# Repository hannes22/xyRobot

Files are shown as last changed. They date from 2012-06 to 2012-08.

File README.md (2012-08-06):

# xyRobot

xyRobot is the Framework for my Robot. [Visit my website for more informations](http://xythobuz.org/index.php?p=rob).

## Software used

 + [Peter Fleurys TWI Library](http://homepage.hispeed.ch/peterfleury/avr-software.html)
 + [Linux Version of Peter Danneggers 'fastboot' by H. C. Zimmerer](http://www.mikrocontroller.net/topic/146638)
 + [A Linux compatible Upload Software for fastboot](http://www.avrfreaks.net/index.php?module=Freaks%20Academy&func=viewItem&item_type=project&item_id=1927)

## xyRobotRemote

xyRobotRemote is a Java App which communicates with the Robot Firmware over a serial port. It allows you to shoot pictures with the Gameboy camera and remote-control the robot. It requires Java 6 and could possibly work with Java 7...

## Protocol

The protocol used by the xyRobot Firmware and xyRobotRemote to remote-control the robot is as follows.

<table>
<tr><th>Character Sequence</th><th>Action</th></tr>
<tr><td>ASCII '?'</td><td>Print Firmware Version String</td></tr>
<tr><td>0x80, x</td><td>Rotate the camera Up/Down to the position indicated by the next byte, x, (0 to 180)</td></tr>
<tr><td>0x81, x</td><td>Same as 0x80, but Left/Right</td></tr>
<tr><td>0x82, r1...r8</td><td>Send picture. Camera Register Settings set with the following 8 bytes.</td></tr>
<tr><td>0x83, d, s, dir</td><td>Drive dist cm with speed speed. Direction Forwards if dir = 1, Backwards if dir = 0</td></tr>
<tr><td>0x84, deg, dir</td><td>Rotate deg Degree. Direction Right if dir = 1, ;eft if dir = 0</td></tr>
<tr><td>0x85, r1...r8</td><td>Send picture with 4bit per Pixel.</td></tr>
<tr><td>0x86</td><td>Returns measured distance.</td></tr>
<tr><td>0x87, r1...r8</td><td>Send picture with 2bit per Pixel.</td></tr>
<tr><td>0x88, r1...r8</td><td>Send picture with 1bit per Pixel.</td></tr>
</table>

New major releases could change this protocol or make additions.

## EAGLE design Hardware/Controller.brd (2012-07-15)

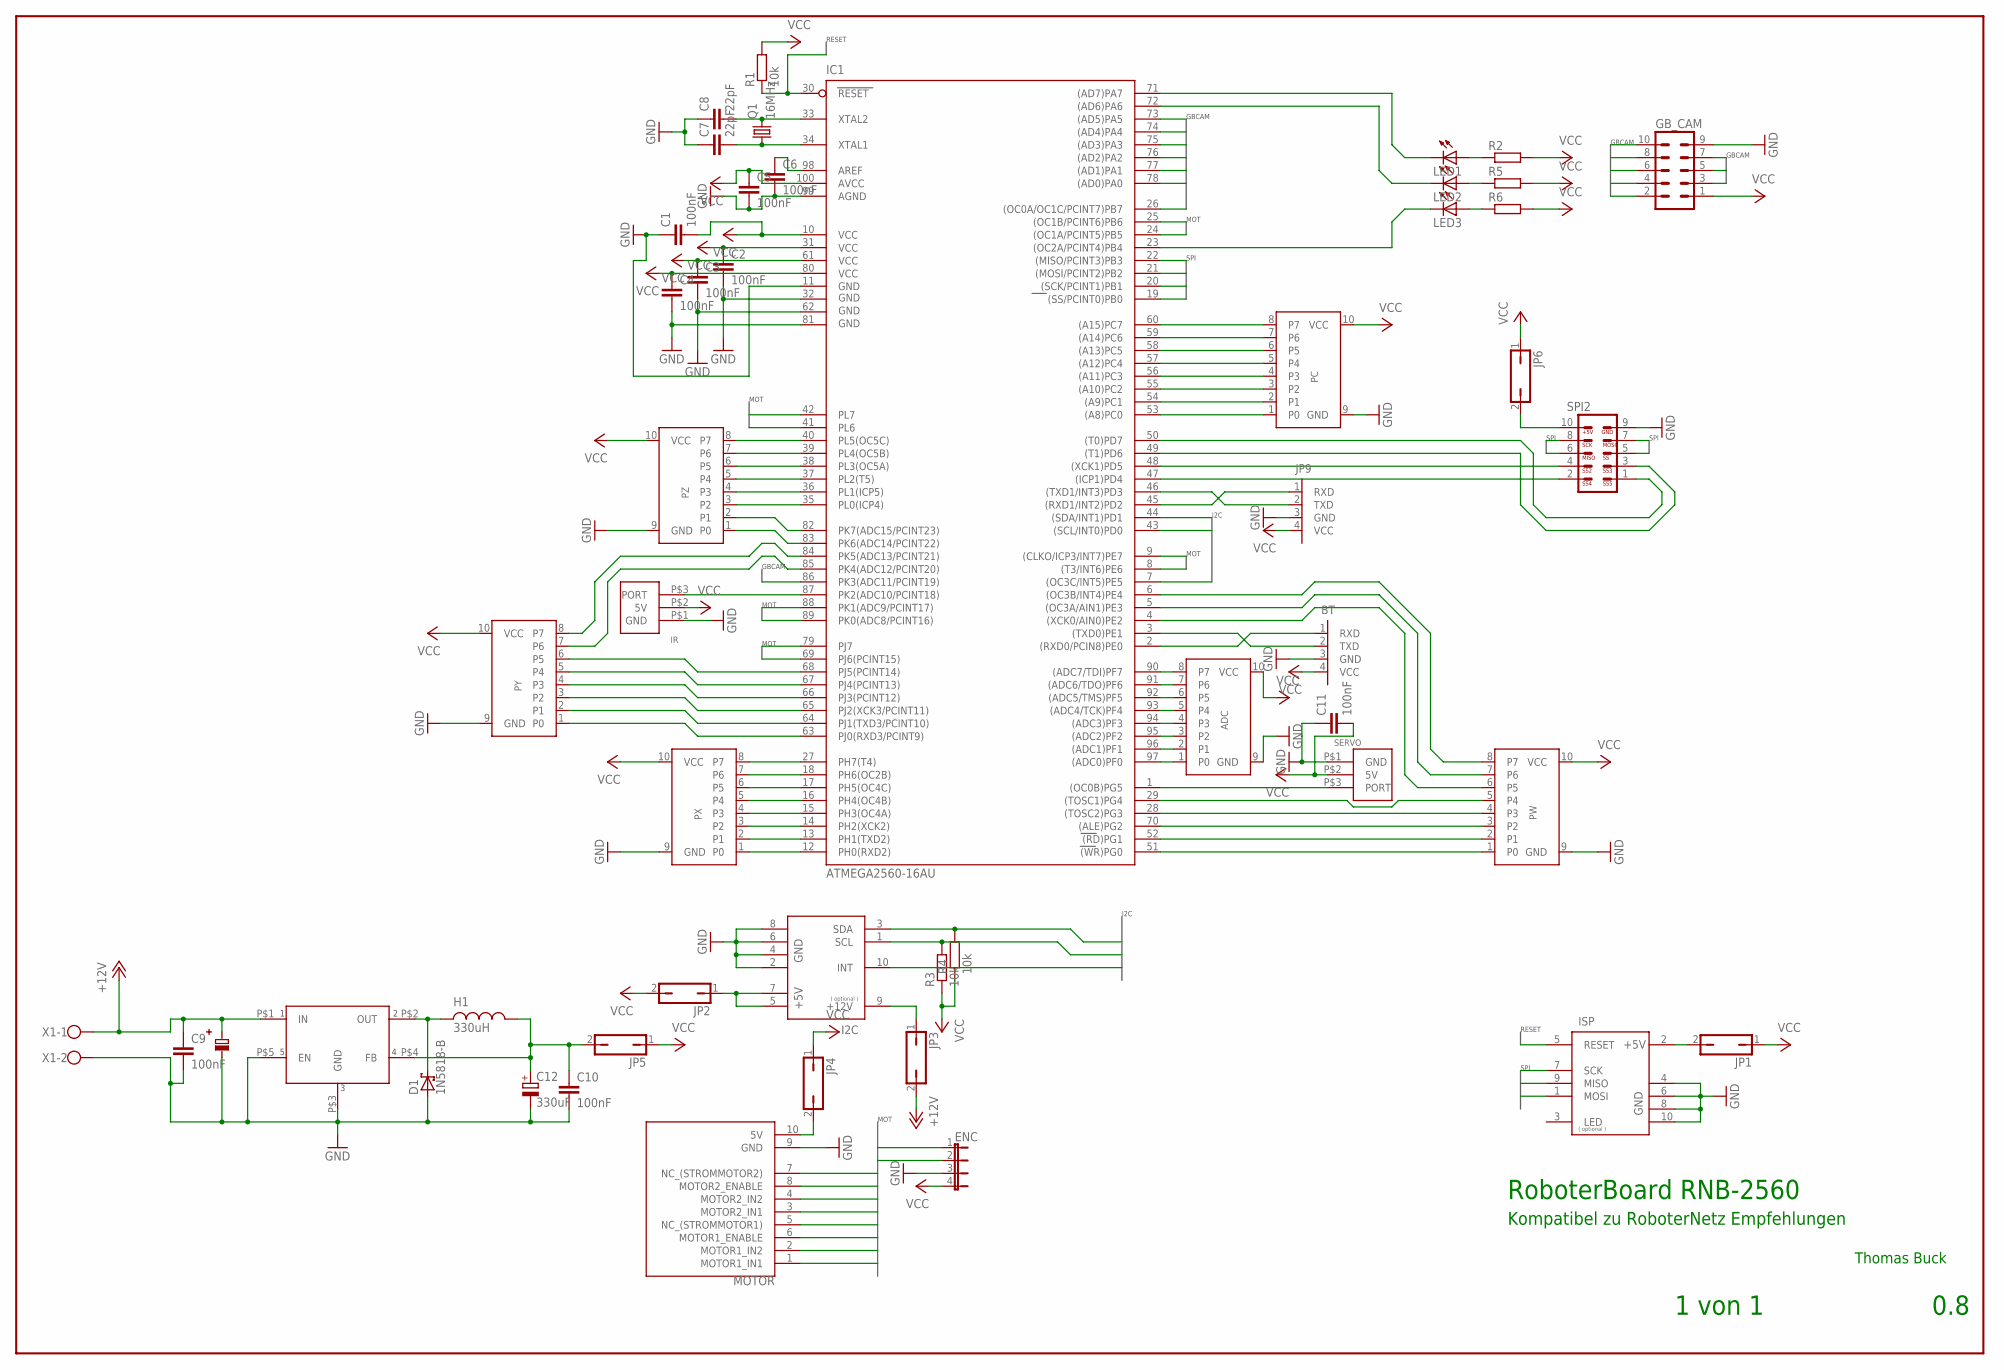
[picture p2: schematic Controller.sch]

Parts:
ADC: PORT; ML10
BT: RS232_TTL; 1X04
C1, C2, C3, C4, C5, C6, C9, C10, C11: 100nF; C0603
C7, C8: 22pF; C0603
C12: 330uF; PANASONIC_F
D1: 1N5818-B; DO41-7.6
ENC: JP4E; JP4
GB_CAM: ML10
H1: 330uH; PISR
I2C: I2C; ML10
IC1: ATMEGA2560-16AU; TQFP100
IR: UNIPORT3POL; 1X3SERVO
ISP: AVR-ISP; ML10
JP1, JP2, JP3, JP4, JP5, JP6: JP1Q; JP1
JP9: RS232_TTL; 1X04
LED1, LED2, LED3: LEDCHIP-LED0603; CHIP-LED0603
LM2576-5: LM2576; TO-220
MOTOR: MOTORSTTCKER10POLRNNORM; ML10
PC: PORT; ML10
PW: PORT; ML10
PX: PORT; ML10
PY: PORT; ML10
PZ: PORT; ML10
Q1: 16MHz; HC49/S
R1, R3, R4: 10k; R0603
R2, R5, R6: R-EU_R0603; R0603
SERVO: UNIPORT3POL; 1X3SERVO
SPI2: SPISTECKER; ML10
U$1: 100uF; ELKO_SMD_6.5
X1: W237-102

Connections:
+12V: C9.1, JP3.2, LM2576-5.P$1 (IN), U$1.P$2, X1.1
ANALOG: GB_CAM.8, IC1.86 (PK3(ADC11/PCINT19))
CLK: GB_CAM.6, IC1.77 ((AD1)PA1)
DATA: GB_CAM.3, IC1.74 ((AD4)PA4)
DATASET: GB_CAM.4, IC1.75 ((AD3)PA3)
DREHL: ENC.1, IC1.9 ((CLKO/ICP3/INT7)PE7)
DREHR: ENC.2, IC1.8 ((T3/INT6)PE6)
GND: ADC.9 (GND), BT.3 (GND), C1.1, C2.2, C3.2, C4.2, C5.2, C6.2, C7.1, C8.1, C9.2, C10.2, C11.1, C12.-, D1.A, ENC.3, GB_CAM.9, I2C.2 (GND), I2C.4 (GND), I2C.6 (GND), I2C.8 (GND), IC1.11 (GND), IC1.32 (GND1), IC1.62 (GND2), IC1.81 (GND3), IC1.99 (AGND), IR.P$1 (GND), ISP.4 (GND), ISP.6 (GND), ISP.8 (GND), ISP.10 (GND), JP9.3 (GND), LM2576-5.P$3 (GND), LM2576-5.P$5 (EN), MOTOR.9 (GND), PC.9 (GND), PW.9 (GND), PX.9 (GND), PY.9 (GND), PZ.9 (GND), SERVO.P$1 (GND), SPI2.9, U$1.P$1, X1.2
IN1L: IC1.42 (PL7), MOTOR.1 (MOTOR1_IN1)
IN1R: IC1.79 (PJ7), MOTOR.3 (MOTOR2_IN1)
IN2L: IC1.41 (PL6), MOTOR.2 (MOTOR1_IN2)
IN2R: IC1.69 (PJ6(PCINT15)), MOTOR.4 (MOTOR2_IN2)
INT: I2C.10 (INT), IC1.7 ((OC3C/INT5)PE5)
MISO: IC1.22 ((MISO/PCINT3)PB3), ISP.9 (MISO), SPI2.6
MOSI: IC1.21 ((MOSI/PCINT2)PB2), ISP.1 (MOSI), SPI2.7
unnamed: IC1.87 (PK2(ADC10/PCINT18)), IR.P$3 (PORT)
unnamed: C6.1, IC1.98 (AREF)
unnamed: C8.2, IC1.33 (XTAL2), Q1.2
unnamed: C7.2, IC1.34 (XTAL1), Q1.1
unnamed: IC1.1 ((OC0B)PG5), SERVO.P$3 (PORT)
unnamed: IC1.60 ((A15)PC7), PC.8 (P7)
unnamed: IC1.59 ((A14)PC6), PC.7 (P6)
unnamed: IC1.58 ((A13)PC5), PC.6 (P5)
unnamed: IC1.57 ((A12)PC4), PC.5 (P4)
unnamed: IC1.56 ((A11)PC3), PC.4 (P3)
unnamed: IC1.55 ((A10)PC2), PC.3 (P2)
unnamed: IC1.54 ((A9)PC1), PC.2 (P1)
unnamed: IC1.53 ((A8)PC0), PC.1 (P0)
unnamed: IC1.12 (PH0(RXD2)), PX.1 (P0)
unnamed: IC1.13 (PH1(TXD2)), PX.2 (P1)
unnamed: IC1.14 (PH2(XCK2)), PX.3 (P2)
unnamed: IC1.15 (PH3(OC4A)), PX.4 (P3)
unnamed: IC1.16 (PH4(OC4B)), PX.5 (P4)
unnamed: IC1.17 (PH5(OC4C)), PX.6 (P5)
unnamed: IC1.18 (PH6(OC2B)), PX.7 (P6)
unnamed: IC1.27 (PH7(T4)), PX.8 (P7)
unnamed: IC1.40 (PL5(OC5C)), PZ.8 (P7)
unnamed: IC1.39 (PL4(OC5B)), PZ.7 (P6)
unnamed: IC1.38 (PL3(OC5A)), PZ.6 (P5)
unnamed: IC1.37 (PL2(T5)), PZ.5 (P4)
unnamed: IC1.36 (PL1(ICP5)), PZ.4 (P3)
unnamed: IC1.35 (PL0(ICP4)), PZ.3 (P2)
unnamed: IC1.82 (PK7(ADC15/PCINT23)), PZ.2 (P1)
unnamed: IC1.83 (PK6(ADC14/PCINT22)), PZ.1 (P0)
unnamed: IC1.63 (PJ0(RXD3/PCINT9)), PY.1 (P0)
unnamed: IC1.64 (PJ1(TXD3/PCINT10)), PY.2 (P1)
unnamed: IC1.65 (PJ2(XCK3/PCINT11)), PY.3 (P2)
unnamed: IC1.66 (PJ3(PCINT12)), PY.4 (P3)
unnamed: IC1.67 (PJ4(PCINT13)), PY.5 (P4)
unnamed: IC1.68 (PJ5(PCINT14)), PY.6 (P5)
unnamed: IC1.85 (PK4(ADC12/PCINT20)), PY.7 (P6)
unnamed: IC1.84 (PK5(ADC13/PCINT21)), PY.8 (P7)
unnamed: IC1.51 ((WR)PG0), PW.1 (P0)
unnamed: IC1.52 ((RD)PG1), PW.2 (P1)
unnamed: IC1.70 ((ALE)PG2), PW.3 (P2)
unnamed: IC1.28 ((TOSC2)PG3), PW.4 (P3)
unnamed: IC1.29 ((TOSC1)PG4), PW.5 (P4)
unnamed: IC1.4 ((XCK0/AIN0)PE2), PW.6 (P5)
unnamed: IC1.5 ((OC3A/AIN1)PE3), PW.7 (P6)
unnamed: IC1.6 ((OC3B/INT4)PE4), PW.8 (P7)
unnamed: JP6.2, SPI2.10
unnamed: IC1.47 ((ICP1)PD4), SPI2.2
unnamed: IC1.48 ((XCK1)PD5), SPI2.4
unnamed: IC1.50 ((T0)PD7), SPI2.1
unnamed: IC1.23 ((OC2A/PCINT4)PB4), LED3.C
unnamed: IC1.72 ((AD6)PA6), LED2.C
unnamed: IC1.71 ((AD7)PA7), LED1.C
unnamed: IC1.49 ((T1)PD6), SPI2.3
unnamed: ISP.2 (+5V), JP1.2
unnamed: I2C.5 (+5V), I2C.7 (+5V), JP2.1
unnamed: I2C.9 (+12V), JP3.1
unnamed: JP4.2, MOTOR.10 (5V)
unnamed: ADC.8 (P7), IC1.90 ((ADC7/TDI)PF7)
unnamed: LED1.A, R2.1
unnamed: LED2.A, R5.1
unnamed: LED3.A, R6.1
unnamed: ADC.7 (P6), IC1.91 ((ADC6/TDO)PF6)
unnamed: ADC.6 (P5), IC1.92 ((ADC5/TMS)PF5)
unnamed: D1.C, H1.P$1, LM2576-5.P$2 (OUT)
unnamed: ADC.5 (P4), IC1.93 ((ADC4/TCK)PF4)
unnamed: ADC.4 (P3), IC1.94 ((ADC3)PF3)
unnamed: ADC.3 (P2), IC1.95 ((ADC2)PF2)
unnamed: ADC.2 (P1), IC1.96 ((ADC1)PF1)
unnamed: ADC.1 (P0), IC1.97 ((ADC0)PF0)
unnamed: IC1.46 ((TXD1/INT3)PD3), JP9.2 (TXD)
unnamed: IC1.45 ((RXD1/INT2)PD2), JP9.1 (RXD)
unnamed: C10.1, C12.+, H1.P$2, JP5.2, LM2576-5.P$4 (FB)
PWML: IC1.25 ((OC1B/PCINT6)PB6), MOTOR.6 (MOTOR1_ENABLE)
PWMR: IC1.24 ((OC1A/PCINT5)PB5), MOTOR.8 (MOTOR2_ENABLE)
READIMG: GB_CAM.7, IC1.78 ((AD0)PA0)
RESET: IC1.30 (RESET), ISP.5 (RESET), R1.1
RX: BT.1 (RXD), IC1.2 ((RXD0/PCIN8)PE0)
SCK: IC1.20 ((SCK/PCINT1)PB1), ISP.7 (SCK), SPI2.8
SCL: I2C.1 (SCL), IC1.43 ((SCL/INT0)PD0), R3.2
SDA: I2C.3 (SDA), IC1.44 ((SDA/INT1)PD1), R4.2
SENSL: IC1.88 (PK1(ADC9/PCINT17)), MOTOR.5 (NC_(STROMMOTOR1))
SENSR: IC1.89 (PK0(ADC8/PCINT16)), MOTOR.7 (NC_(STROMMOTOR2))
SERVO: GB_CAM.10, IC1.26 ((OC0A/OC1C/PCINT7)PB7)
SS: IC1.19 ((SS/PCINT0)PB0), SPI2.5
START: GB_CAM.2, IC1.73 ((AD5)PA5)
SYSRES: GB_CAM.5, IC1.76 ((AD2)PA2)
TX: BT.2 (TXD), IC1.3 ((TXD0)PE1)
VCC: ADC.10 (VCC), BT.4 (VCC), C1.2, C2.1, C3.1, C4.1, C5.1, C11.2, ENC.4, GB_CAM.1, IC1.10 (VCC), IC1.31 (VCC1), IC1.61 (VCC2), IC1.80 (VCC3), IC1.100 (AVCC), IR.P$2 (5V), JP1.1, JP2.2, JP4.1, JP5.1, JP6.1, JP9.4 (VCC), PC.10 (VCC), PW.10 (VCC), PX.10 (VCC), PY.10 (VCC), PZ.10 (VCC), R1.2, R2.2, R3.1, R4.1, R5.2, R6.2, SERVO.P$2 (5V)

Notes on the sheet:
RoboterBoard RNB-2560
Thomas Buck
Kompatibel zu RoboterNetz Empfehlungen
0.8
MOT
I2C
SPI
RESET
GBCAM
1 von 1

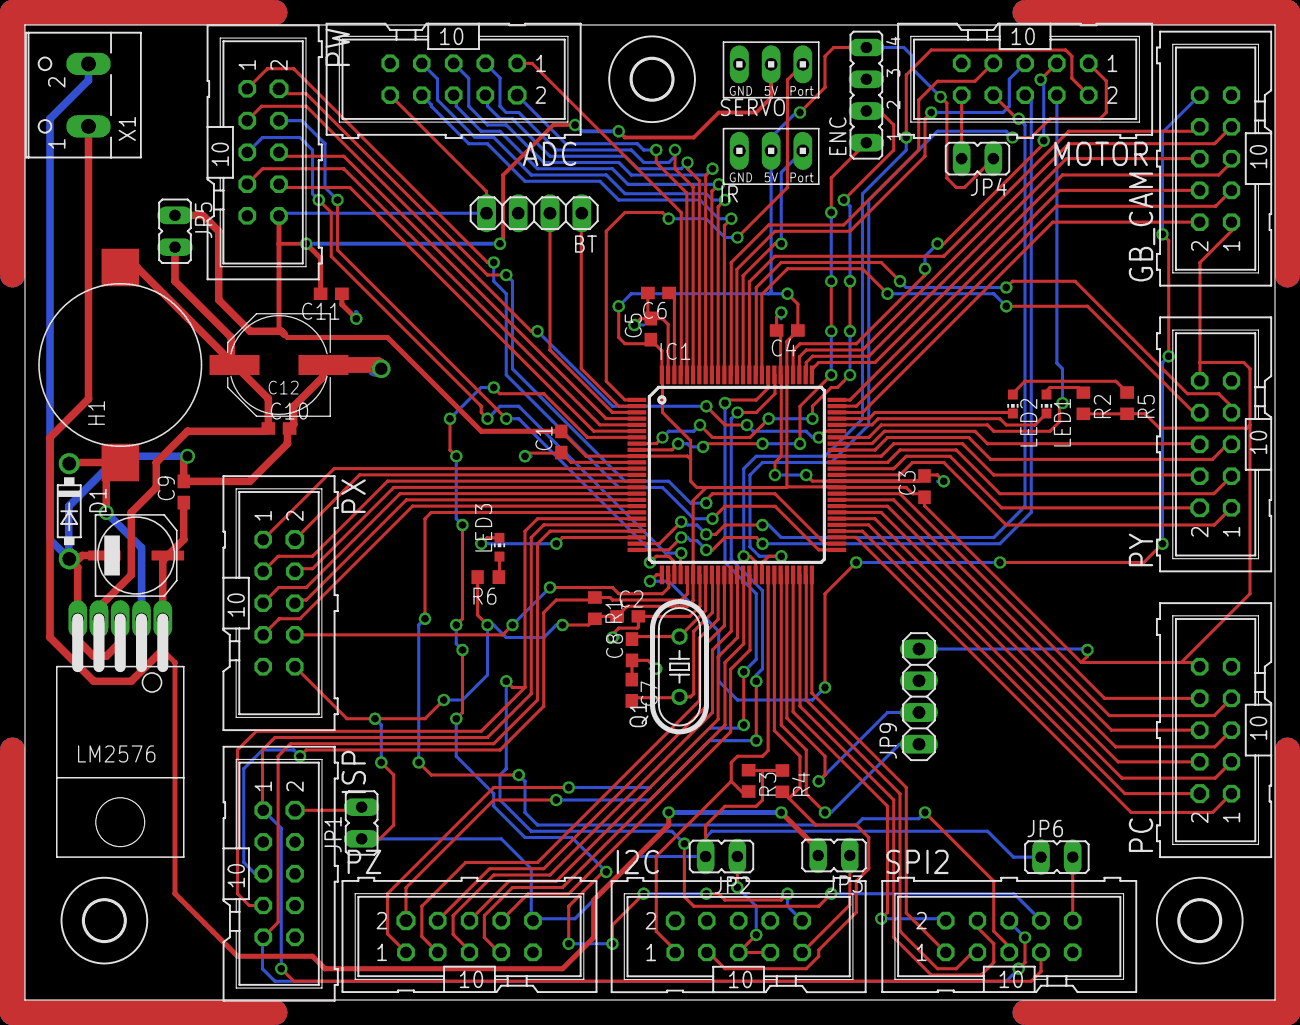
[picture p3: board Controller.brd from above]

Board: 2 copper layers, 100.0 x 78.0 mm, 53 parts (0 on the bottom side), 103 nets.

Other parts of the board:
U$2, U$3, U$4: 3,2

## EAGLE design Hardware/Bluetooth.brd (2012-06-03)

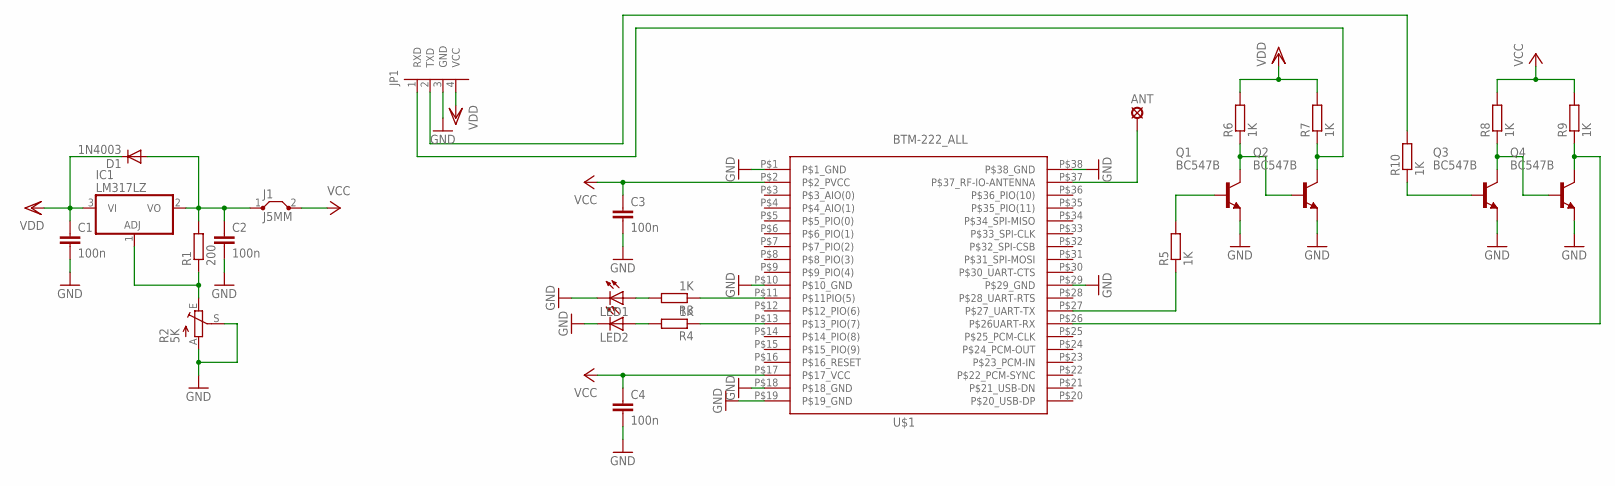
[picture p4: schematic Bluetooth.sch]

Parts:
ANT: SE14
C1, C2, C3, C4: 100n; C050-030X075
D1: 1N4003; DO41-10
IC1: LM317LZ; TO92
J1: J5MM; 05
JP1: RS232_TTL; 1X04
LED1, LED2: LED3MM
Q1, Q2, Q3, Q4: BC547B; TO92
R1: 200; 0207/10
R2: 5K; PT-10S
R3, R4, R5, R6, R7, R8, R9, R10: 1K; 0207/10
U$1: BTM-222_ALL; BTM-222

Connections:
GND: C1.2, C2.2, C3.2, C4.2, JP1.3 (GND), LED1.K (C), LED2.K (C), Q1.1 (E), Q2.1 (E), Q3.1 (E), Q4.1 (E), R2.A, R2.S, U$1.P$1 (P$1_GND), U$1.P$10 (P$10_GND), U$1.P$18 (P$18_GND), U$1.P$19 (P$19_GND), U$1.P$29 (P$29_GND), U$1.P$38 (P$38_GND)
unnamed: R3.1, U$1.P$11 (P$11PIO(5))
unnamed: LED1.A, R3.2
unnamed: IC1.1 (ADJ), R1.1, R2.E
unnamed: R4.1, U$1.P$13 (P$13_PIO(7))
unnamed: LED2.A, R4.2
unnamed: Q1.2 (B), R5.2
unnamed: JP1.1 (RXD), Q2.3 (C), R7.1
unnamed: Q1.3 (C), Q2.2 (B), R6.1
unnamed: JP1.2 (TXD), R10.2
unnamed: Q3.2 (B), R10.1
unnamed: R5.1, U$1.P$27 (P$27_UART-TX)
unnamed: Q3.3 (C), Q4.2 (B), R8.1
unnamed: Q4.3 (C), R9.1, U$1.P$26 (P$26UART-RX)
unnamed: ANT.MP, U$1.P$37 (P$37_RF-IO-ANTENNA)
unnamed: C2.1, D1.A, IC1.2 (VO), J1.1, R1.2
VCC: C3.1, C4.1, J1.2, R8.2, R9.2, U$1.P$2 (P$2_PVCC), U$1.P$17 (P$17_VCC)
VDD: C1.1, D1.C, IC1.3 (VI), JP1.4 (VCC), R6.2, R7.2

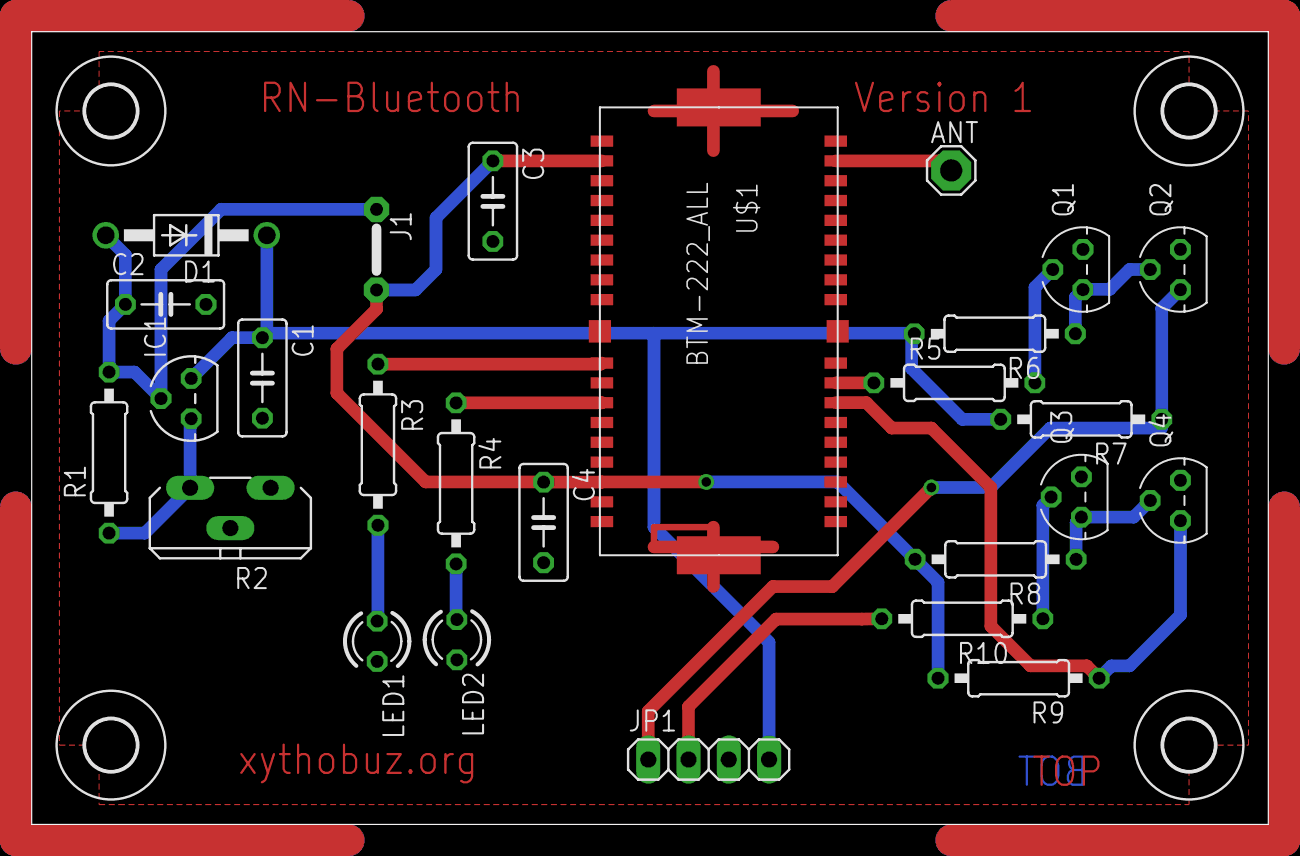
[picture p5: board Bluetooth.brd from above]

Board: 2 copper layers, 78.0 x 50.0 mm, 30 parts (0 on the bottom side), 18 nets.

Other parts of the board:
U$2, U$3, U$4, U$5: 3,2

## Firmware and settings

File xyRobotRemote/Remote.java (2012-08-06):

/*
 * Remote.java
 *
 * Copyright 2012 Thomas Buck <xythobuz@me.com>
 *
 * This file is part of xyRobot.
 *
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
 * You should have received a copy of the GNU General Public License
 * along with xyRobot.  If not, see <http://www.gnu.org/licenses/>.
 */

import javax.swing.*;
import javax.swing.event.*;
import java.awt.*;
import java.awt.event.*;
import javax.imageio.*;
import java.io.*;

public class Remote extends JFrame implements ActionListener, ChangeListener,
												MouseListener, KeyListener,
												ComponentListener {

	private final String version = "1.0";
	public int width = 485 + DistanceWindow.width;
	public int height = 420;
	public final int xOff = 0;
	public final int yOff = 0;

	private PaintCanvas canvas = null;

	private JPanel bigPanel = null;

	private JPanel serialStuff = null;
	private JComboBox portSelector = null;
	private JButton openPort = null;
	private JButton closePort = null;

	private JLabel status = null;

	private JPanel cameraStuff = null;
	private JButton trigger = null;
	private JSlider depth = null;
	private JButton save = null;
	private JSlider camMoveX = null;
	private JSlider camMoveY = null;
	private JButton camSettings = null;

	private JPanel driveStuff = null;
	private JTextField dist = null;
	private JLabel distCM = null;
	private JTextField speed = null;
	private JCheckBox reverse = null;
	private JButton drive = null;
	private JTextField degree = null;
	private JLabel degreeDeg = null;
	private JButton turnRight = null;
	private JButton turnLeft = null;

	public CanvasWindow canvasWin = null;
	public DistanceWindow distanceWin = null;

	public SerialCommunicator serial = null;

	private final int UP    = 0;
	private final int DOWN  = 1;
	private final int LEFT  = 2;
	private final int RIGHT = 3;

	private int registers[] = {
		0x00, // Z & Offset
		0x03, // N & VH & Gain
		0x00, // C1
		0x01, // C0
		0x01, // P
		0x00, // M
		0x01, // X
		0x04  // E & I & V
	};

	public Remote() {
		super("xyRobotRemote");

		serial = new SerialCommunicator(this);

		setBounds(xOff, yOff, width, height);
		setDefaultCloseOperation(JFrame.EXIT_ON_CLOSE);
		setLayout(null);
		addComponentListener(this);
		Container c = getContentPane();

		distanceWin = new DistanceWindow(this, 80);
		distanceWin.setBounds(0, 0, distanceWin.width, height);
		distanceWin.setVal(80);
		c.add(distanceWin);

		bigPanel = new JPanel();
		bigPanel.setBounds(distanceWin.width, 0, width - distanceWin.width, height);
		bigPanel.addKeyListener(this);
		bigPanel.setLayout(new FlowLayout());
		c.add(bigPanel);

		canvas = new PaintCanvas(128, 128, 2);
		// canvas.setBounds(10, 10, 256, 256);
		canvas.setPreferredSize(new Dimension(256, 256));
		canvas.setBorder(BorderFactory.createLoweredBevelBorder());
		canvas.addMouseListener(this);
		canvas.addKeyListener(this);
		bigPanel.add(canvas);

		cameraStuff = new JPanel();
		cameraStuff.setBorder(BorderFactory.createTitledBorder("Camera"));
		// cameraStuff.setBounds(275, 105, 215, 225);
		cameraStuff.setPreferredSize(new Dimension(215, 225));
		cameraStuff.setLayout(null);
		cameraStuff.addKeyListener(this);
		bigPanel.add(cameraStuff);

		serialStuff = new JPanel();
		serialStuff.setBorder(BorderFactory.createTitledBorder("Serial"));
		// serialStuff.setBounds(275, 5, 215, 95);
		serialStuff.setPreferredSize(new Dimension(215, 95));
		serialStuff.setLayout(null);
		serialStuff.addKeyListener(this);
		bigPanel.add(serialStuff);

		driveStuff = new JPanel();
		driveStuff.setBorder(BorderFactory.createTitledBorder("Drive"));
		// driveStuff.setBounds(275, 330, 215, 100);
		driveStuff.setPreferredSize(new Dimension(215, 100));
		driveStuff.setLayout(null);
		driveStuff.addKeyListener(this);
		bigPanel.add(driveStuff);

		status = new JLabel("<html>Initializing xyRobotRemote " + version);
		// status.setBounds(10, 275, 256, 50);
		// status.setSize(new Dimension(256, 50));
		status.addKeyListener(this);
		status.setBorder(BorderFactory.createLoweredBevelBorder());
		bigPanel.add(status);

		// --------------------------------

		String[] ports = HelperUtility.getPorts();
		if ((ports == null) || (ports.length == 0)) {
			showError("No serial ports found!");
			System.exit(1);
		}
		java.util.List<String> list = java.util.Arrays.asList(ports);
		java.util.Collections.reverse(list);
		ports = (String[])list.toArray();
		for (int i = 0; i < ports.length; i++) {
			if (ports[i].equals("/dev/tty.xyRobot-DevB") && (i != 0)) {
				String tmp = ports[0];
				ports[0] = ports[i];
				ports[i] = tmp;
			}
		}
		portSelector = new JComboBox(ports);
		portSelector.setBounds(5, 20, 205, 30);
		portSelector.addKeyListener(this);
		serialStuff.add(portSelector);

		openPort = new JButton();
		openPort.setText("Open");
		openPort.setBounds(5, 55, 100, 30);
		openPort.addActionListener(this);
		openPort.addKeyListener(this);
		serialStuff.add(openPort);

		closePort = new JButton();
		closePort.setText("Close");
		closePort.setBounds(105, 55, 100, 30);
		closePort.addActionListener(this);
		closePort.addKeyListener(this);
		serialStuff.add(closePort);

		trigger = new JButton();
		trigger.setText("Shoot Pic");
		trigger.setBounds(60, 15, 140, 30);
		trigger.addActionListener(this);
		trigger.addKeyListener(this);
		cameraStuff.add(trigger);

		camSettings = new JButton();
		camSettings.setText("Cam Registers");
		camSettings.setBounds(60, 95, 140, 30);
		camSettings.addActionListener(this);
		camSettings.addKeyListener(this);
		cameraStuff.add(camSettings);

		save = new JButton();
		save.setText("Save image");
		save.setBounds(60, 130, 140, 30);
		save.addActionListener(this);
		save.addKeyListener(this);
		cameraStuff.add(save);

		depth = new JSlider(0, 3);
		depth.setValue(3);
		depth.addChangeListener(this);
		depth.setBounds(60, 50, 140, 40);
		depth.setMajorTickSpacing(1);
		depth.setMajorTickSpacing(1);
		depth.setPaintTicks(true);
		java.util.Hashtable<Integer, JLabel> table = new java.util.Hashtable<Integer, JLabel>();
		table.put(0, new JLabel("1"));
		table.put(1, new JLabel("2"));
		table.put(2, new JLabel("4"));
		table.put(3, new JLabel("8"));
		depth.setLabelTable(table);
		depth.setPaintLabels(true);
		depth.addKeyListener(this);
		cameraStuff.add(depth);

		camMoveY = new JSlider(JSlider.VERTICAL, 0, 180, 40); // vertical cam movement slider
		camMoveY.setBounds(5, 15, 60, 205);
		camMoveY.addChangeListener(this);
		camMoveY.setMajorTickSpacing(45);
		camMoveY.setMinorTickSpacing(45);
		camMoveY.setPaintTicks(true);
		camMoveY.addKeyListener(this);
		cameraStuff.add(camMoveY);

		camMoveX = new JSlider(0, 180);
		camMoveX.setValue(95);
		camMoveX.setBounds(60, 165, 150, 60);
		camMoveX.addChangeListener(this);
		camMoveX.setMajorTickSpacing(45);
		camMoveX.setMinorTickSpacing(45);
		camMoveX.setPaintTicks(true);
		camMoveX.addKeyListener(this);
		cameraStuff.add(camMoveX);

		dist = new JTextField();
		dist.setText("100");
		dist.setBounds(5, 20, 40, 30);
		dist.addKeyListener(this);
		driveStuff.add(dist);

		distCM = new JLabel();
		distCM.setText("cm");
		distCM.setBounds(45, 20, 20, 30);
		distCM.addKeyListener(this);
		driveStuff.add(distCM);

		speed = new JTextField();
		speed.setText("200");
		speed.setBounds(70, 20, 40, 30);
		speed.addKeyListener(this);
		driveStuff.add(speed);

		reverse = new JCheckBox();
		reverse.setBounds(115, 20, 30, 30);
		reverse.addKeyListener(this);
		driveStuff.add(reverse);

		drive = new JButton();
		drive.setText("Drive");
		drive.setBounds(150, 20, 60, 30);
		drive.addActionListener(this);
		drive.addKeyListener(this);
		driveStuff.add(drive);

		degree = new JTextField();
		degree.setText("180");
		degree.setBounds(15, 55, 40, 30);
		degree.addKeyListener(this);
		driveStuff.add(degree);

		degreeDeg = new JLabel();
		degreeDeg.setText("\u00b0");
		degreeDeg.setBounds(55, 55, 30, 30);
		degreeDeg.addKeyListener(this);
		driveStuff.add(degreeDeg);

		turnLeft = new JButton();
		turnLeft.setText("L");
		turnLeft.setBounds(80, 55, 50, 30);
		turnLeft.addActionListener(this);
		turnLeft.addKeyListener(this);
		driveStuff.add(turnLeft);

		turnRight = new JButton();
		turnRight.setText("R");
		turnRight.setBounds(135, 55, 50, 30);
		turnRight.addActionListener(this);
		turnRight.addKeyListener(this);
		driveStuff.add(turnRight);

		setControls(false); // Turn everything off
		setVisible(true);

		// Shutdown Hook to close an opened serial port
		Runtime.getRuntime().addShutdownHook(new Thread(new ShutdownThread(this), "Serial Closer"));

		log("Rendering Image");
		ImageTest t = new ImageTest("splash.png");
		canvas.setData(t.getData());
		fixImageColor(false); // Converting color-pics leads to dark images...
	}

	// ------------------------------
	// |            Misc            |
	// ------------------------------

	public void setControls(boolean open) {
		closePort.setEnabled(open);
		openPort.setEnabled(!open);
		trigger.setEnabled(open);
		// save.setEnabled(open);
		camMoveX.setEnabled(open);
		camMoveY.setEnabled(open);
		// camSettings.setEnabled(open);
		drive.setEnabled(open);
		reverse.setEnabled(open);
		speed.setEnabled(open);
		dist.setEnabled(open);
		degree.setEnabled(open);
		turnRight.setEnabled(open);
		turnLeft.setEnabled(open);
		depth.setEnabled(open);
	}

	private void setDistanceView() {
		serial.writeChar(0x86);
		short[] dist = serial.readData(1);
		distanceWin.setVal(dist[0]);
	}

	public void showError(String error) {
		JOptionPane.showMessageDialog(this, error, "Error", JOptionPane.ERROR_MESSAGE);
		log("ERROR: " + error);
	}

	public void showInfo(String info) {
		JOptionPane.showMessageDialog(this, info, "Info", JOptionPane.INFORMATION_MESSAGE);
		log(info);
	}

	public void log(String log) {
		String s = status.getText();
		if (s.length() > 50) {
			status.setText("<html>" + log);
		} else {
			status.setText(s + " -- " + log);
		}
	}

	private void readFile(String f) {
		try {
			FileReader fr = new FileReader(f);
			readFile(fr);
		} catch (Exception e) {
			System.out.println("Error: " + e.getMessage());
		}
	}

	private void readFile(InputStream is) {
		InputStreamReader isr = new InputStreamReader(is);
		readFile(isr);
	}

	private void readFile(Reader r) {
		try {
			BufferedReader br = new BufferedReader(r);
			java.util.ArrayList<String> l = new java.util.ArrayList<String>();
			String str, delimiter = ",\n";
			while ((str = br.readLine()) != null) {
				java.util.StringTokenizer t = new java.util.StringTokenizer(str, delimiter);
				while (t.hasMoreTokens()) {
					String element = t.nextToken();
					l.add(element);
				}
			}
			canvas.setData(l.toArray());
		} catch (Exception e) {
			System.out.println("Error: " + e.getMessage());
		}
	}

	private	void printImageStats() {
		int average = 0, max = 0, min = 256;
		for (int i = 0; i < 128; i++) {
			for (int j = 0; j < 128; j++) {
				if (canvas.data[i][j] > max) {
					max = canvas.data[i][j];
				}
				if (canvas.data[i][j] < min) {
					min = canvas.data[i][j];
				}

				average += canvas.data[i][j];
			}
		}
		average /= (128 * 128);

		System.out.println("Current Image Statistics:");
		System.out.println("Average: " + average);
		System.out.println("Maximum: " + max);
		System.out.println("Minimum: " + min);
	}

	private void fixImageColor(boolean print) {
		int max = 0;
		for (int i = 0; i < 128; i++) {
			for (int j = 0; j < 128; j++) {
				if (canvas.data[i][j] > max) {
					max = canvas.data[i][j];
				}
			}
		}
		if (max < 255) {
			double f = (double)255 / (double)max;
			for (int i = 0; i < 128; i++) {
				for (int j = 0; j < 128; j++) {
					canvas.data[i][j] *= f;
					if (canvas.data[i][j] > 255) {
						canvas.data[i][j] = 255;
					}
				}
			}
			canvas.repaint();
			if (print) System.out.printf("Image fixed. Factor: %.2f\n", f);
		}
	}

	// ------------------------------
	// | Calls for external windows |
	// ------------------------------

	public void distanceWindowKilled() {
		distanceWin = new DistanceWindow(this);
		if (serial.isOpen()) {
			setDistanceView();
		}
	}

	public void cameraWindowKilled() {
		canvasWin = null;
		canvas.setToRefresh(null);
	}

	public void registersUpdated(int[] regs) {
		registers = regs;
	}

	// ------------------------------
	// |         Listeners          |
	// ------------------------------

	public void actionPerformed(ActionEvent e) {
		if (e.getSource().equals(turnRight)) {
			turnButton(true);
		} else if (e.getSource().equals(turnLeft)) {
			turnButton(false);
		} else if (e.getSource().equals(drive)) {
			driveButton();
		} else if (e.getSource().equals(camSettings)) {
			camSettingsButton();
		} else if (e.getSource().equals(trigger)) {
			triggerButton();
		} else if (e.getSource().equals(openPort)) {
			openButton();
		} else if (e.getSource().equals(closePort)) {
			closeButton();
		} else if (e.getSource().equals(save)) {
			saveButton();
		}
	}

	public void keyTyped(KeyEvent e) {
		switch (e.getKeyChar()) {
			case 'r':
				canvas.randomize();
				break;

			case 's':
				printImageStats();
				break;

			case 'd':
				fixImageColor(true);
				break;

			case 'w':
				System.out.println(getWidth() + "x" + getHeight());
				break;
		}
	}
	public void keyPressed(KeyEvent e) {}
	public void keyReleased(KeyEvent e) {}

	public void mouseClicked(MouseEvent e) {
		if (e.getSource().equals(canvas)) {
			if (e.getClickCount() == 2) {
				if (canvasWin == null) {
					canvasWin = new CanvasWindow(this);
					canvas.setToRefresh(canvasWin.getCanvas());
					canvasWin.getCanvas().setData(canvas.data);
				}
			}
		}
	}
	public void mousePressed(MouseEvent e) {}
	public void mouseReleased(MouseEvent e) {}
	public void mouseEntered(MouseEvent e) {}
	public void mouseExited(MouseEvent e) {}

	public void componentResized(ComponentEvent e) {
		width = getWidth();
		height = getHeight();

		DistanceWindow dW = new DistanceWindow(this, 80);
		dW.setVal(distanceWin.value);
		getContentPane().remove(distanceWin);
		distanceWin = dW;
		distanceWin.setBounds(0, 0, distanceWin.width, height);
		getContentPane().add(distanceWin);

		bigPanel.setBounds(distanceWin.width, 0, width - distanceWin.width, height);

		repaint();
	}
	public void componentHidden(ComponentEvent e) {}
	public void componentMoved(ComponentEvent e) {}
	public void componentShown(ComponentEvent e) {}

	public void stateChanged(ChangeEvent e) {
		// For the sliders
		if (e.getSource().equals(camMoveY)) {
			if (!((JSlider)e.getSource()).getValueIsAdjusting()) {
				// New Y-Axis position
				serial.writeChar(0x80);
				serial.writeChar(camMoveY.getValue());
			}
		} else if (e.getSource().equals(camMoveX)) {
			if (!((JSlider)e.getSource()).getValueIsAdjusting()) {
				// New X-Axis position
				serial.writeChar(0x81);
				serial.writeChar(camMoveX.getValue());
			}
		}
	}

	// ------------------------------
	// |      Button Handler        |
	// ------------------------------

	private void triggerButton() {
		int length = 0;
		switch(depth.getValue()) {
			case 0:
				serial.writeChar(0x88);
				length = 64 * 32;
				break;
			case 1:
				serial.writeChar(0x87);
				length = 64 * 64;
				break;
			case 2:
				serial.writeChar(0x85);
				length = 128 * 64;
				break;
			case 3:
				serial.writeChar(0x82);
				length = 128 * 128;
				break;
		}
		log("Writing registers.");
		for (int i = 0; i < 8; i++) {
			serial.writeChar(registers[i]);
		}
		log("Getting picture data");
		short[] d = serial.readData(length);
		if (d == null) {
			if (serial.lastError == serial.TIMEOUT) {
				showError("Timed out!");
			} else {
				showError("Error while reading!");
			}
		} else {
			canvas.setData(d, 8);
			log("Getting distance");
			setDistanceView();
			log("Done!");
		}
	}

	private void turnButton(boolean turnRight) {
		serial.writeChar(0x84); // command, degree, dir
		serial.writeChar((char)Integer.valueOf(degree.getText(), 10).intValue());
		String temp = "";
		if (turnRight) {
			serial.writeChar(1);
			temp = "Right";
		} else {
			serial.writeChar(0);
			temp = "Left";
		}
		log("Turning " + degree.getText() + "\u00b0 " + temp);
	}

	private void driveButton() {
		serial.writeChar(0x83); // command, dist, speed, dir
		serial.writeChar((char)Integer.valueOf(dist.getText(), 10).intValue());
		serial.writeChar((char)Integer.valueOf(speed.getText(), 10).intValue());
		String temp = "";
		if (reverse.isSelected()) {
			temp = "Reverse";
			serial.writeChar(0);
		} else {
			serial.writeChar(1);
			temp = "Forward";
		}
		log("Driving " + dist.getText() + "cm with " + speed.getText() + " " + temp);
	}

	private void camSettingsButton() {
		Registers reg = new Registers(this, registers);
		reg.setVisible(true);
	}

	private void openButton() {
		// Open Port, enable controls
		if (serial.openPort((String)portSelector.getSelectedItem())) {
			setControls(true);
			log("Connected!");
		} else {
			showError("Could not open port " + (String)portSelector.getSelectedItem());
		}
	}

	private void closeButton() {
		if (serial.isOpen())
			serial.closePort();
		setControls(false);
		log("Connection closed.");
	}

	private void saveButton() {
		// Render canvas into image
		JFileChooser chooser = new JFileChooser();
		if (chooser.showSaveDialog(this) == JFileChooser.APPROVE_OPTION) {
			String path = chooser.getSelectedFile().getAbsolutePath();
			if (!path.endsWith(".png")) {
				path += ".png";
			}
			File f = new File(path);
			try {
				ImageIO.write(canvas.paintIntoImage(), "png", f);
			} catch (Exception ex) {
				showError("Could not write!" + ex.getMessage());
			}
		}
	}

	public static void main(String[] args) {
		Remote r = new Remote();
	}
}

// Close serial connection on shutdown
class ShutdownThread implements Runnable {
	private Remote remote = null;

	public ShutdownThread(Remote r) {
		remote = r;
	}

	public void run() {
		if (remote.serial != null) {
			if (remote.serial.isOpen()) {
				remote.serial.closePort();
			}
		}
	}
}

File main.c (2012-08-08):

/*
 * main.c
 *
 * Copyright 2012 Thomas Buck <xythobuz@me.com>
 *
 * This file is part of xyRobot.
 *
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
 * You should have received a copy of the GNU General Public License
 * along with xyRobot.  If not, see <http://www.gnu.org/licenses/>.
 */
#include <stdint.h>
#include <stdlib.h>
#include <util/delay.h>
#include <avr/interrupt.h>
#include <avr/io.h>
#include <avr/pgmspace.h>
#include <avr/wdt.h>

#include <twi.h>
#include <time.h>
#include <serial.h>
#include <motor.h>
#include <misc.h>
#include <adc.h>
#include <cam.h>
#include <mem.h>
#include <serialHandler.h>
#include <menuHandler.h>
#include <tasks.h>

// Remember: Strings to the lcd should not end with \n
// Timer 0 (8 bit): Servo PWM
// Timer 1 (16bit): Motor Speed PWM
// Timer 2 (8 bit): System Time
// Timer 3 (16bit): Unused
// Timer 4 (16bit): Unused
// Timer 5 (16bit): Unused

// LED 0 & 1 used as motor display.
// LED 2 is heartbeat task

char buffer[BUFFERSIZE]; // Used as global string buffer
char versionString[] PROGMEM = "xyRobot 0.9\n";
uint8_t upDownPos = MIDDLE;
uint8_t leftRightPos = CENTER;

void heartbeat(void) {
	ledToggle(2);
}

void watchdog(void) {
	wdt_reset();
}

int main(void) {

	MCUSR = 0;
	wdt_disable();

	ledInit();
	ledToggle(2); // LED on
	driveInit();
	twiInit();
	lcdInit();
	serialInit(UART_BAUD_SELECT(38400,16000000L), 8, NONE, 1);
	adcInit(AINT2); // Voltage reference: 2,56V
	camInit();
	memInit();
	initSystemTimer();

	sei(); // Enable interrupts

	menuInit();
	ledToggle(2); // LED off
	wdt_enable(WDTO_2S); // Watchdog reset after 2s.

	initTasks();
	addFullTimeTask(&remoteHandler, "Remote");
	addFullTimeTask(&menuHandler, "LCD Menu");
	addTimedTask(&heartbeat, 4); // Executed every 4*128ms=512ms
	addTimedTask(&watchdog, 12); // Executed every 1536ms, reset after 2000...
	runTasks();

	return 0;
}

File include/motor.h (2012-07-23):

/*
 * motor.h
 *
 * Copyright 2011 Thomas Buck <xythobuz@me.com>
 *
 * This file is part of xyRobot.
 *
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
 * You should have received a copy of the GNU General Public License
 * along with xyRobot.  If not, see <http://www.gnu.org/licenses/>.
 */

#ifndef motor_h
#define motor_h

// Motor Directions
#define FORWARD 1
#define BACKWARD 2
#define RIGHT 3
#define LEFT 4

// Servo positions
#define CENTER 95
#define LR_CENTER CENTER
#define MIDDLE 40
#define UD_CENTER MIDDLE

#define TURNSPEED 128
// define one, not both
#define CMPERTICK 1
// #define TICKSPERCM 1
// distance between wheels in cm
#define WHEELDISTANCE 20

#define UPDOWNSERVO PB7
#define UPDOWNPORT PORTB
#define UPDOWNDDR DDRB
#define LEFTRIGHTSERVO PG5
#define LEFTRIGHTPORT PORTG
#define LEFTRIGHTDDR DDRG

// ISR every 10 microseconds
// --> 16.000.000 / Prescaler / OCRValue = 100.000
// --> 16.000.000 /     1     /   160    = 100.000
// --> 16.000.000 /     8     /    20    = 100.000
// Number fix:
// [50;200] = OFFSET + ( [0;180] * FACTOR / QUOTIENT )

// No follow 2 configurations:
// (ISR every 10us or every 100us)
// The commented-out definitions are for
// high-resolution servo movements.
// The now used config needs only 1/10th of
// the CPU-Time but has less resolution.

#define OCRVAL 200 // #define OCRVAL 20
#define COUNTMAX 200 // #define COUNTMAX 2000
#define FACTOR 1 // #define FACTOR 83
#define QUOTIENT 12 // #define QUOTIENT 100
#define OFFSET 5 // #define OFFSET 50
#define SERVOSTEPWIDTH QUOTIENT

#define PRESCALER (1 << CS01)
#define SERVODURATION 100

void driveInit(void);
// dir = FORWARD or BACKWARD
void drive(uint16_t cm, uint8_t speed, uint8_t dir);
// dir = RIGHT or LEFT
void turn(uint16_t degree, uint8_t dir);
uint8_t driveDone(void);

uint8_t getDistance(void);

void rotateInit(void);
void rotateUpDown(uint8_t pos); // From 0 to 180
void rotateLeftRight(uint8_t pos);

#endif

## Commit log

2011-07-30 Added readme, schematics and layout
    [Bluetooth.brd, Bluetooth.sch, Controller.brd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]
2012-01-01 Pics are too big for ram...
    [cam.h]
2012-01-03 Added servo support
2012-06-03 Circuit Diagram and Layout are now in EAGLE 6 format.
    [Bluetooth.brd, Bluetooth.sch, Controller.brd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]
2012-07-14 New servo code. More LCD Menu.
2012-07-15 Added external SRAM
    [Controller.brd, Controller.sch, RAM.sch]
2012-07-18 Servos need less cpu time.
2012-07-21 Extended menu. Fixed Ram.
    [main.c]
2012-07-23 Servo is turned off after reaching position.
2012-07-28 ADC now with better offset voltage.
    Also included utility to test canvas with different pics.
2012-07-28 Restructured camera code.
2012-07-28 Easier flashing with auto reset.
    [cam.h, main.c]
2012-08-07 Watchdog reset now in own task…
    [main.c]
2012-08-30 App Bundling not compatible with Mountain Lion!

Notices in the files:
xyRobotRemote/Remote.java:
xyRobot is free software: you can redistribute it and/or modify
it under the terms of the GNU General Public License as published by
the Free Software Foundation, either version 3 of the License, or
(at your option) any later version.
